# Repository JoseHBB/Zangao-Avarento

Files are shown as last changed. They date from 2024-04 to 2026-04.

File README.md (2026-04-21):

# Zangão Avarento

Wiki pública do projeto de TCC de automação industrial focado no desenvolvimento de um drone de baixo custo controlado por smartphone.

<p align="center">
  Drone final
</p>

## Sobre

O Zangão Avarento nasceu como um projeto de TCC com o objetivo de demonstrar que era possível montar uma plataforma de voo com controle por celular utilizando componentes acessíveis, fabricação própria da placa e desenvolvimento do firmware e do aplicativo.

Este repositório funciona como a documentação pública do projeto. Aqui estão reunidos o histórico de desenvolvimento, os arquivos de eletrônica e PCB, os códigos do Arduino, os arquivos do aplicativo, imagens do processo e o relatório final.

## Navegação da wiki

- [Visão geral do projeto](Projeto.md)
- [Construção mecânica e estrutura](Construcao_Mecanica.md)
- [Firmware e lógica de controle no Arduino](Arduino_Reference.md)
- [Esquema elétrico e PCB no KiCad](KicadSchemePCB_Reference.md)
- [Aplicativo Android](App_Reference.md)
- [Galeria de imagens](Galeria.md)
- [Arquivos e recursos do repositório](Arquivos_e_Recursos.md)

## Estrutura resumida

- `Arduino/`: códigos e rascunhos do firmware.
- `App/`: arquivo-fonte do app no MIT App Inventor e APK gerado.
- `Kicad Scheme-PCB/`: projeto eletrônico e layout da placa.
- `Images/`: imagens de protótipos, placa, estrutura e esquemas.
- `Videos/`: vídeos de testes das funções e demonstração de voo.
- `Apresentação TCC Drone.pptx`: apresentação final do TCC.
- `Relatório.pdf`: versão do relatório final do trabalho.

## Criadores do projeto

- Guilherme Faria da Silva
- João Vinícius da Silva
- José Henrique Batista Borges

## Contato

Qualquer dúvida sobre o projeto:

- [José Henrique](https://github.com/JoseHBB)
- `josehenribb@gmail.com`

## Licença

Este repositório utiliza a licença MIT para fins de estudo, pesquisa, uso pessoal e uso comercial conforme os termos do arquivo [LICENSE](LICENSE).

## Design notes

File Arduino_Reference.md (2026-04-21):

# Firmware E Lógica De Controle No Arduino

## Visão geral

Os arquivos da pasta `Arduino/` registram a base do firmware utilizado para o controle dos motores do drone. O código está organizado como um conjunto de trechos que mostram a estrutura do projeto, a definição dos pinos, a comunicação Bluetooth e as funções de movimento.

## Arquivos disponíveis

- `Arduino/Drone_codigo.ino`: definições principais, variáveis e comunicação serial por software.
- `Arduino/Drone_codigo_functions.ino`: funções de acionamento dos motores.
- `Arduino/Drone_codigo_comments.ino`: descrição textual dos comandos previstos.
- `Arduino/Drone_codigo_base.ino`: `setup()` e `loop()` com leitura Bluetooth e despacho de comandos.

Com a atualização mais recente do repositório, os quatro arquivos acima agora representam o fluxo completo da lógica de controle usada nos testes do projeto.

## Base eletrônica controlada pelo firmware

Pelos arquivos do projeto, o Arduino Nano atua como controlador principal do sistema. O firmware foi pensado para:

- receber comandos de um smartphone;
- interpretar esses comandos por Bluetooth;
- gerar sinais PWM para quatro motores;
- preparar a lógica para controle de movimentação básica.

## Mapeamento dos motores

No arquivo `Drone_codigo.ino`, os motores são associados aos seguintes pinos PWM:

- `motor_frente_dir`: pino `6`
- `motor_traz_dir`: pino `9`
- `motor_frente_esq`: pino `10`
- `motor_traz_esq`: pino `11`

Também foi declarada a interface Bluetooth com:

- `SoftwareSerial HC_06(2,3);`

Isso indica a intenção de usar o módulo HC-06 nos pinos digitais `2` e `3`.

## Variáveis de velocidade

O código separa a intensidade dos movimentos por tipo de ação:

- `vel_subir`
- `vel_descer`
- `vel_xy`
- `vel_giro`

Essa divisão simplifica o ajuste da potência aplicada aos motores em cada situação.

Também aparecem variáveis de estado para controlar o comportamento geral:

- `stoped`: flag de estado para indicar se o sistema está parado.
- `vel_atual`: referência da velocidade atual aplicada ao conjunto.
- `vel_parado` e `vel_start`: base para manter rotação mínima e partida.

## Fluxo de execução do firmware

O funcionamento foi dividido em um fluxo simples e direto:

1. `setup()`
2. inicializa serial USB (`Serial.begin(9600)`)
3. inicializa serial Bluetooth (`HC_06.begin(9600)`)
4. inicializa MPU-6050 (`start_gyro()`)

No `loop()` o código repete o ciclo:

1. faz leitura do sensor (`read_gyro()`)
2. espera um comando Bluetooth chegar (`HC_06.available()`)
3. converte o comando recebido para inteiro (`parseInt()`)
4. usa `switch` para disparar a ação correspondente
5. se o comando não estiver mapeado, executa `parado_no_ar()`

Esse formato deixa o firmware orientado a comando remoto: cada número recebido representa uma função de controle de atitude/movimento.

## Mapeamento de comandos Bluetooth

No `switch` de `Drone_codigo_base.ino`, os códigos são:

- `100`: `start()`
- `101`: `stop()`
- `102`: `subir()`
- `103`: `descer()`
- `104`: `frente()`
- `105`: `traz()`
- `106`: `direita()`
- `107`: `esquerda()`
- `108`: `girar_horario()`
- `109`: `girar_anti_horario()`

## Funções implementadas

As funções presentes em `Drone_codigo_functions.ino` representam os movimentos básicos do drone:

- `start()`: liga todos os motores com potência fixa inicial.
- `stop()`: desliga todos os motores.
- `subir()`: aplica a mesma potência de subida aos quatro motores.
- `descer()`: aplica a mesma potência de descida aos quatro motores.
- `frente()`: aumenta a potência dos motores traseiros.
- `traz()`: aumenta a potência dos motores dianteiros.
- `direita()`: aumenta a potência dos motores da esquerda.
- `esquerda()`: aumenta a potência dos motores da direita.
- `girar_horario()`: altera dois motores para rotação no sentido horário.
- `girar_anti_horario()`: altera dois motores para rotação no sentido anti-horário.

Na prática, os movimentos são obtidos por diferença de PWM entre pares de motores:

- subida/descida: alteração conjunta dos quatro motores;
- translação horizontal: aumenta dois motores e reduz os opostos;
- guinada (yaw): aumenta motores de uma diagonal e reduz os da diagonal contrária.

Esse método é consistente com o comportamento esperado de um quadricóptero em configuração de quatro rotores com controle diferencial de empuxo.

## Leitura do giroscópio/acelerômetro

As funções de sensor já estão presentes no código:

- `start_gyro()`: inicia o MPU-6050 e define faixas de medição/filtro.
- `read_gyro()`: captura aceleração (`a`), rotação (`g`) e temperatura (`temp`).

Mesmo sem malha de controle fechada implementada nesta versão, essa base já prepara o firmware para evolução com estabilização automática e correção por realimentação.

## Lógica documentada nos comentários

O arquivo `Drone_codigo_comments.ino` resume os seis blocos de comportamento previstos:

1. ligar todos os motores em velocidade pré-definida;
2. desligar todos os motores;
3. subir;
4. descer;
5. movimentação horizontal nos eixos `X` e `Y`;
6. movimentação rotativa.

## Escopo do que está no repositório

Os arquivos disponíveis representam a implementação funcional de controle por comandos Bluetooth e organização da lógica por funções de voo/movimento. A parte de estabilização por sensor ainda aparece como base de leitura e preparação da arquitetura.

A documentação é útil para entender a arquitetura adotada:

- um comando vindo do app;
- a interpretação desse comando no Arduino;
- a seleção da função de movimento;
- o ajuste da potência dos motores via PWM.

## Relação com o hardware

O firmware conversa diretamente com a eletrônica descrita em [KicadSchemePCB_Reference.md](KicadSchemePCB_Reference.md):

- os sinais PWM saem do Arduino Nano;
- esses sinais acionam os MOSFETs da placa;
- os MOSFETs controlam a alimentação dos motores;
- o HC-06 recebe os comandos do aplicativo;
- o giroscópio foi previsto como fonte de dados para evolução do controle.

## Leitura recomendada

- [Visão geral do projeto](Projeto.md)
- [Esquema elétrico e PCB no KiCad](KicadSchemePCB_Reference.md)
- [Aplicativo Android](App_Reference.md)

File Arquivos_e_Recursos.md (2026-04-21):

# Arquivos E Recursos Do Repositório

## Objetivo desta página

Esta página resume o que existe no repositório e para que serve cada grupo de arquivos. A ideia é facilitar o uso deste projeto como uma wiki pública.

## Pastas principais

### `Arduino/`

Arquivos relacionados ao firmware e à lógica de controle:

- `Drone_codigo.ino`
- `Drone_codigo_base.ino`
- `Drone_codigo_comments.ino`
- `Drone_codigo_functions.ino`

Leitura recomendada: [Arduino_Reference.md](Arduino_Reference.md)

### `App/`

Arquivos do aplicativo Android:

- `Controlador_de_motor_via_BT.aia`
- `Controlador_de_motor_via_BT.apk`

Leitura recomendada: [App_Reference.md](App_Reference.md)

### `Kicad Scheme-PCB/`

Arquivos do projeto eletrônico e da placa:

- `drone_pcb_V1.4.kicad_sch`
- `drone_pcb_V1.4.kicad_pcb`
- `drone_pcb_V1.4.kicad_pro`
- `drone_pcb_V1.4.kicad_prl`

Leitura recomendada: [KicadSchemePCB_Reference.md](KicadSchemePCB_Reference.md)

### `Images/`

Imagens usadas para documentar a evolução do projeto, a estrutura e a placa:

- `Projeto - 2022.jpg`
- `Drone_Cima_Old.png`
- `Drone_Cima_New.png`
- `Drone_Frente.jpg`
- `Carcaça.jpg`
- `Hélice.jpg`
- `Esquema_Eletrico.png`
- `PCB_Blueprint.png`
- `PCB_Front.jpg`
- `PCB_Back.jpg`
- `PCB_Only.jpg`

Leitura recomendada: [Galeria.md](Galeria.md)

### `Videos/`

Vídeos de demonstração e validação do funcionamento:

- `Video - Teste funções.mp4`
- `Video - Voo.mp4`

Leitura recomendada: [Galeria.md](Galeria.md)

### `Apresentação TCC Drone.pptx`

Arquivo da apresentação final do TCC usado para defesa e exposição do projeto.

## Arquivos de documentação

- `README.md`: página inicial da wiki.
- `Projeto.md`: visão geral e histórico do TCC.
- `Construcao_Mecanica.md`: documentação da parte estrutural.
- `Arduino_Reference.md`: referência do firmware.
- `KicadSchemePCB_Reference.md`: referência da eletrônica e PCB.
- `App_Reference.md`: referência do aplicativo.
- `Galeria.md`: central de imagens do projeto.

## Arquivos adicionais

- `Relatório.pdf`: relatório final do TCC.
- `Apresentação TCC Drone.pptx`: apresentação final do TCC.
- `Planilha com os preços 2022.xlsx`: levantamento de custos e componentes.
- `LICENSE`: licença do repositório.
- `Videos/Video - Teste funções.mp4`: demonstração das funções de comando.
- `Videos/Video - Voo.mp4`: demonstração prática de voo.

## Como usar este repositório

Se o objetivo for entender o projeto como um todo, a melhor sequência é:

1. começar por [README.md](README.md);
2. seguir para [Projeto.md](Projeto.md);
3. consultar as páginas específicas de mecânica, firmware, eletrônica e app;
4. usar [Galeria.md](Galeria.md) para apoio visual;
5. consultar a apresentação em `Apresentação TCC Drone.pptx`;
6. abrir o `Relatório.pdf` para a versão acadêmica consolidada.

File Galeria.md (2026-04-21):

# Galeria De Imagens

## Protótipo inicial

<p align="center">
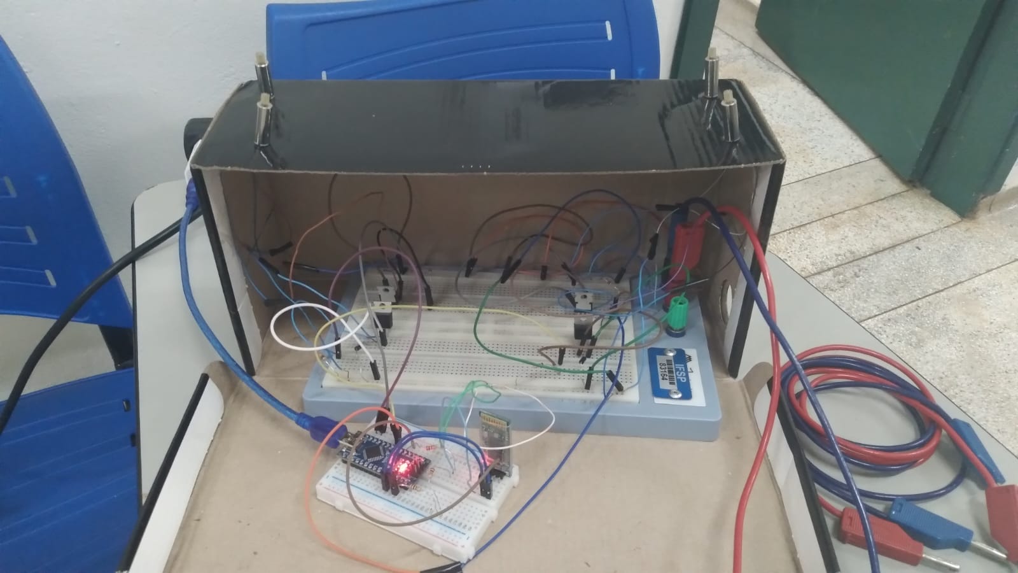
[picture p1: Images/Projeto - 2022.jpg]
Protótipo 2022
  <br/>
  Estrutura inicial usada para demonstrar o controle dos motores.
</p>

## Evolução da estrutura

<p align="center">
  Drone vista superior antiga<br/>
  Versão anterior da estrutura.
</p>

<p align="center">
  Drone vista superior nova<br/>
  Versão mais refinada da estrutura.
</p>

<p align="center">
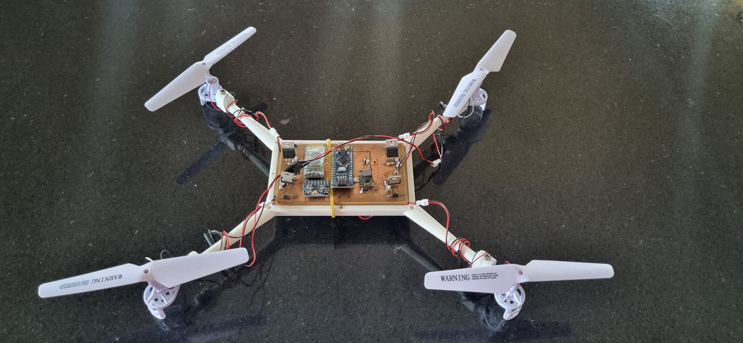
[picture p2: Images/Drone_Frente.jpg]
Drone vista frontal
  <br/>
  Vista frontal do drone.
</p>

## Peças mecânicas

<p align="center">
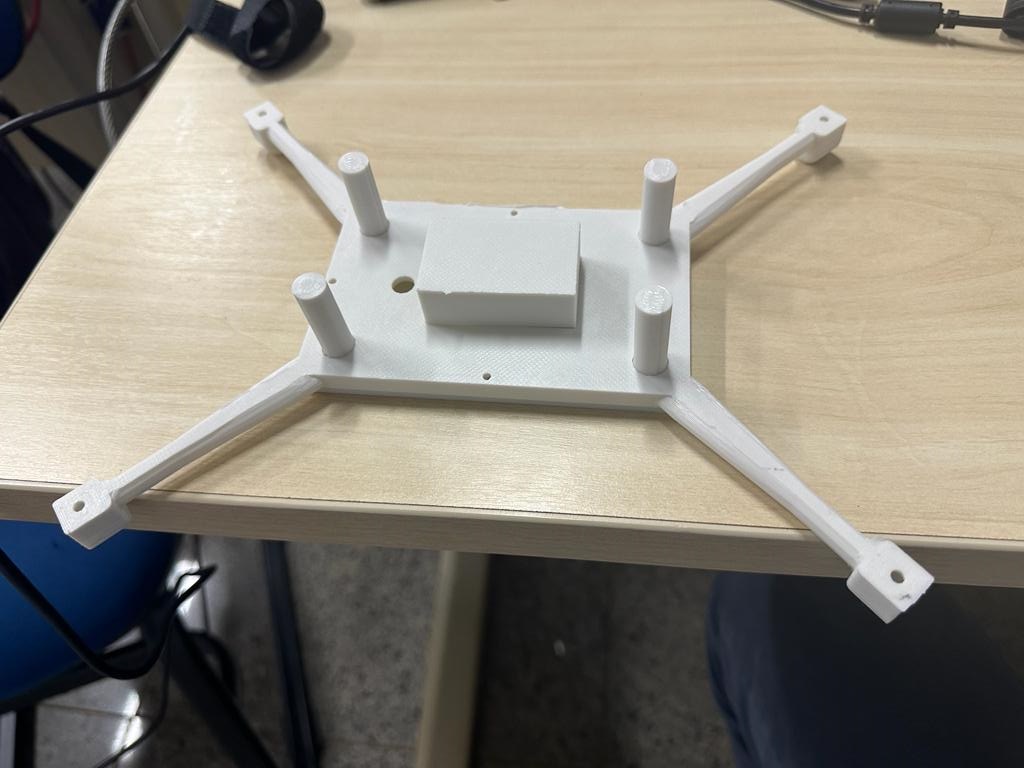
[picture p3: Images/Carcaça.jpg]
Carcaça
  <br/>
  Carcaça do projeto.
</p>

<p align="center">
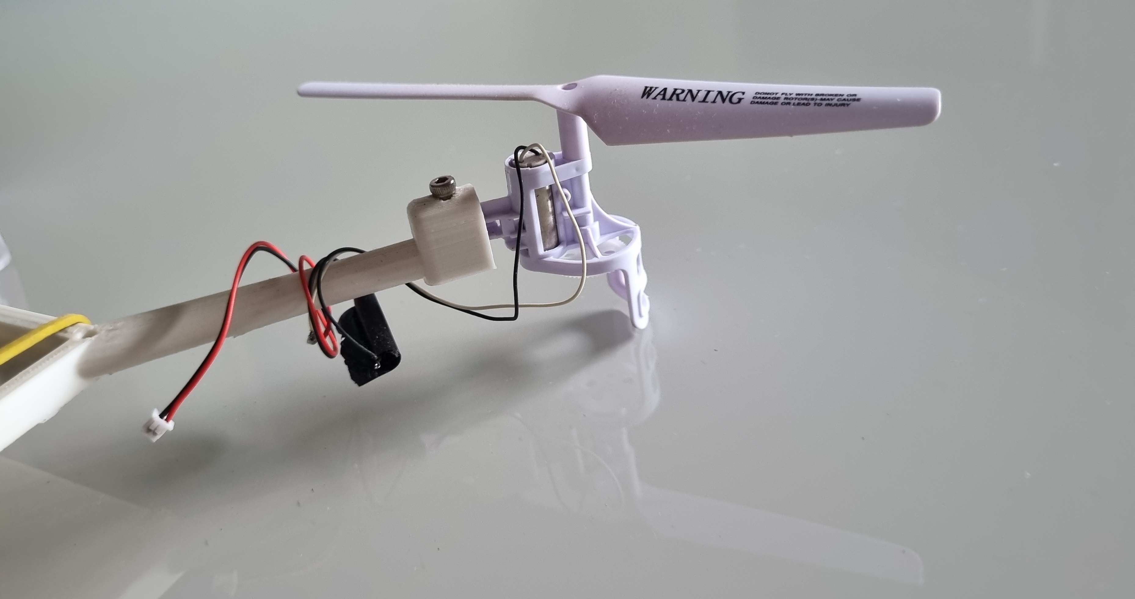
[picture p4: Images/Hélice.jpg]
Helice
  <br/>
  Hélice utilizada.
</p>

## Eletrônica

<p align="center">
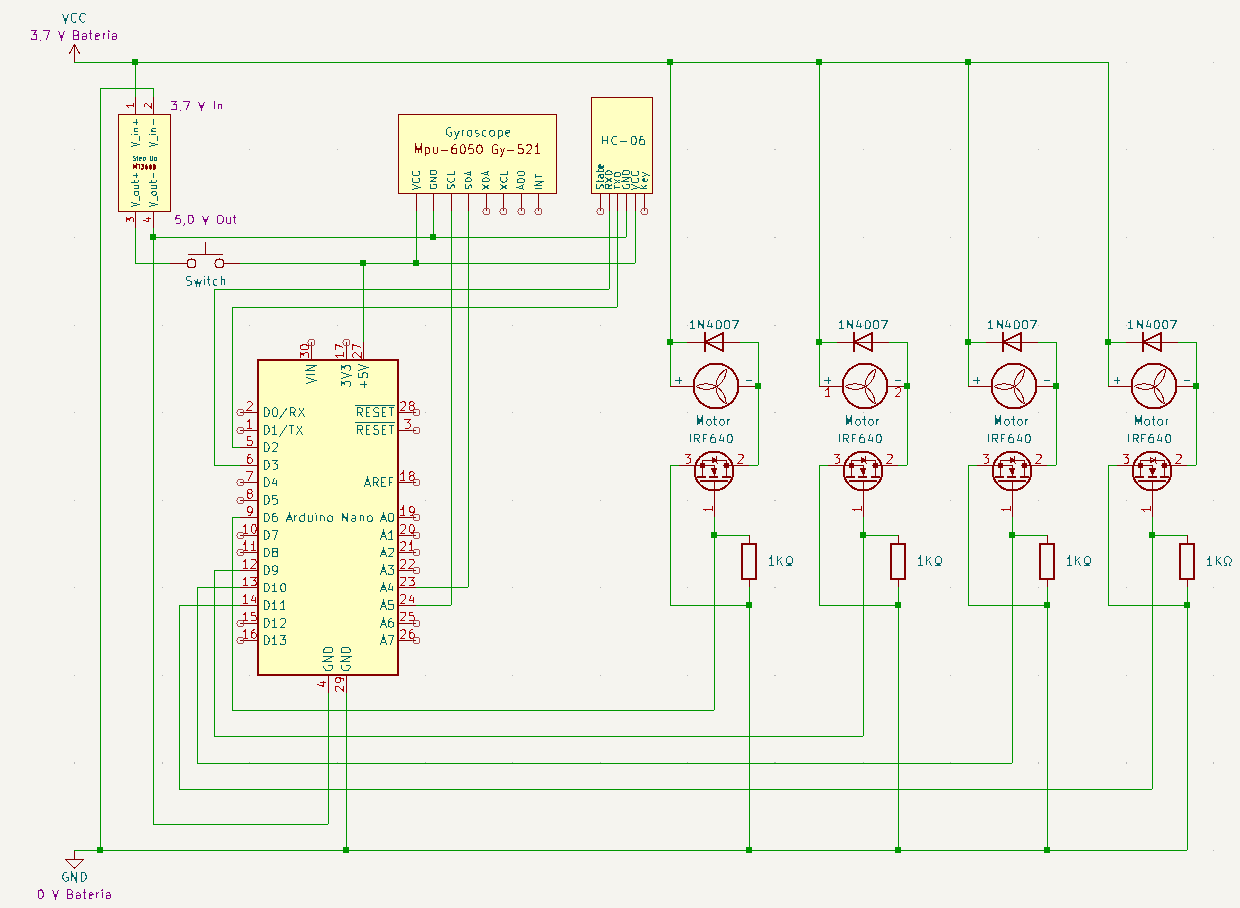
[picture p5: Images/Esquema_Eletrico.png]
Esquema elétrico
  <br/>
  Esquema elétrico do sistema.
</p>

<p align="center">
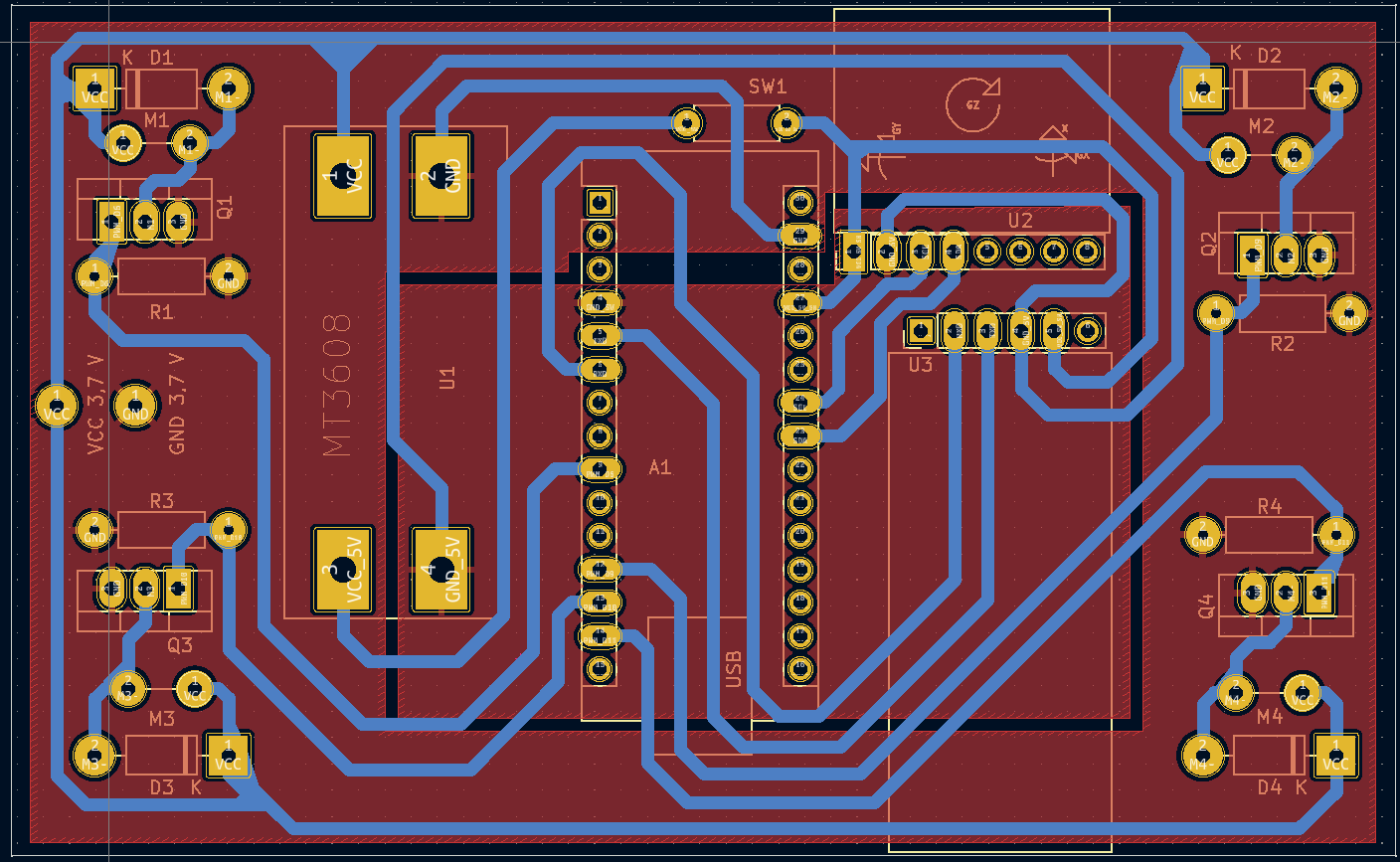
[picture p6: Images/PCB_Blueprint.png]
Blueprint PCB
  <br/>
  Blueprint da PCB.
</p>

<p align="center">
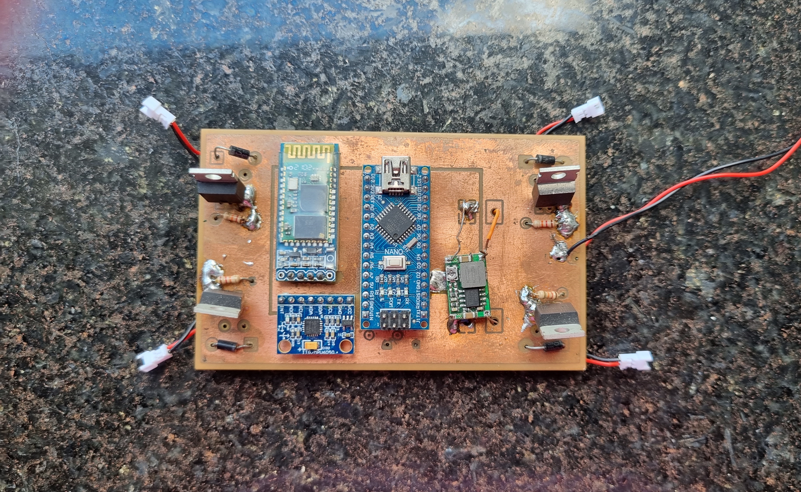
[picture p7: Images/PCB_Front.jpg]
PCB front
  <br/>
  Face frontal da placa.
</p>

<p align="center">
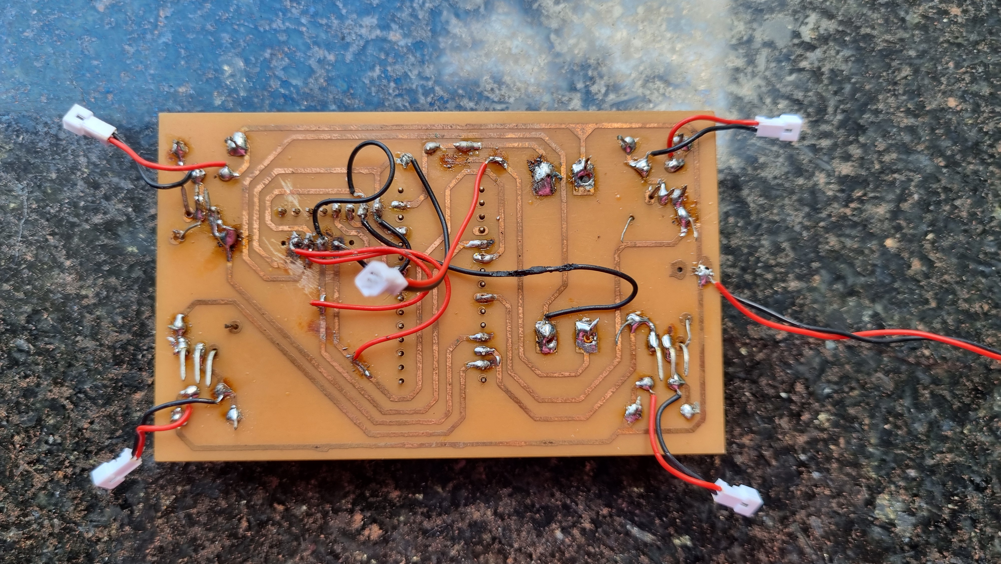
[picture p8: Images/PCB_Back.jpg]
PCB back
  <br/>
  Face traseira da placa.
</p>

<p align="center">
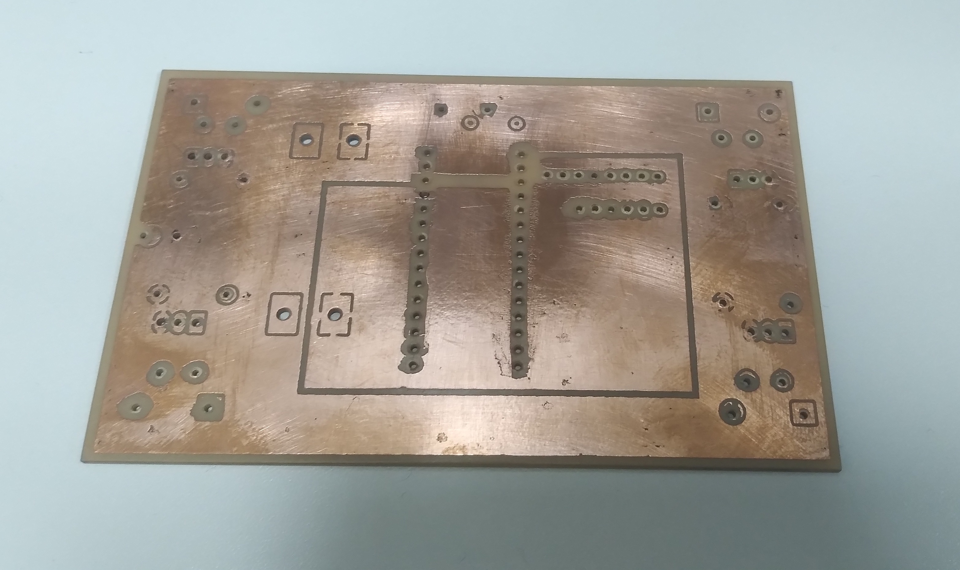
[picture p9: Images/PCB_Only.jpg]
PCB only
  <br/>
  PCB isolada.
</p>

## Vídeos de funcionamento

Os testes e demonstrações mais recentes também estão documentados em vídeo:

- [Teste das funções de controle](Videos/Video%20-%20Teste%20fun%C3%A7%C3%B5es.mp4)
- [Demonstração de voo](Videos/Video%20-%20Voo.mp4)

## Navegação relacionada

- [Visão geral do projeto](Projeto.md)
- [Construção mecânica e estrutura](Construcao_Mecanica.md)
- [Esquema elétrico e PCB no KiCad](KicadSchemePCB_Reference.md)

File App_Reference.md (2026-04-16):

# Aplicativo Android

## Visão geral

O controle do Zangão Avarento foi pensado para ser feito por smartphone, mantendo o projeto alinhado com a proposta de baixo custo. Em vez de um rádio controle dedicado, o grupo utilizou comunicação Bluetooth entre o celular e o sistema embarcado.

## Arquivos disponíveis

Na pasta `App/` existem dois artefatos:

- `App/Controlador_de_motor_via_BT.aia`: projeto editável do MIT App Inventor.
- `App/Controlador_de_motor_via_BT.apk`: aplicativo Android compilado para instalação.

## Função do aplicativo no projeto

O aplicativo atua como interface do usuário para enviar comandos ao Arduino por meio do módulo HC-06. Dentro da arquitetura do projeto, ele cumpre três papéis:

- oferecer um meio simples de controle;
- substituir um controle remoto dedicado;
- demonstrar integração entre software mobile e sistema embarcado.

## Tecnologia utilizada

O desenvolvimento foi feito no MIT App Inventor, uma plataforma visual bastante adequada para protótipos educacionais e experimentais. Isso combina com a proposta do TCC porque reduz a barreira de desenvolvimento do lado mobile e acelera a criação da interface.

## Relação com o firmware

O app depende da lógica descrita em [Arduino_Reference.md](Arduino_Reference.md):

- o celular envia comandos;
- o módulo Bluetooth HC-06 recebe esses dados;
- o Arduino interpreta a informação recebida;
- o firmware ajusta os motores conforme a ação desejada.

## Relação com a eletrônica

No projeto eletrônico documentado em [KicadSchemePCB_Reference.md](KicadSchemePCB_Reference.md), o módulo Bluetooth identificado é o `HC-06`. Isso confirma que a aplicação Android foi pensada especificamente para controle sem fio via Bluetooth serial.

## Observação sobre edição

O arquivo `.aia` é o ponto de partida para estudar ou alterar o aplicativo. O `.apk` é útil para instalação e demonstração, mas não substitui o arquivo-fonte do App Inventor.

## Leitura recomendada

- [Visão geral do projeto](Projeto.md)
- [Firmware e lógica de controle no Arduino](Arduino_Reference.md)
- [Arquivos e recursos do repositório](Arquivos_e_Recursos.md)

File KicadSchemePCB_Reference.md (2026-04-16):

# Esquema Elétrico E PCB No KiCad

## Visão geral

O projeto eletrônico do Zangão Avarento foi desenvolvido no KiCad 6.0 e reúne a parte de alimentação, controle, comunicação e acionamento dos motores. O repositório guarda tanto os arquivos editáveis do projeto quanto imagens exportadas do esquema e da placa.

## Arquivos disponíveis

Na pasta `Kicad Scheme-PCB/` estão os arquivos principais:

- `drone_pcb_V1.4.kicad_sch`: esquema elétrico.
- `drone_pcb_V1.4.kicad_pcb`: layout da placa.
- `drone_pcb_V1.4.kicad_pro`: projeto KiCad.
- `drone_pcb_V1.4.kicad_prl`: preferências locais do projeto.

## Arquitetura eletrônica identificada

Pelos arquivos do KiCad, a placa foi estruturada em torno dos seguintes blocos:

- `Arduino Nano`: controlador principal.
- `HC-06`: comunicação Bluetooth com o smartphone.
- `MPU-6050 / GY-521`: módulo de giroscópio e acelerômetro.
- `MT3608`: conversor step-up para elevação da tensão.
- `4 x IRF640`: MOSFETs para acionamento dos motores.
- `Switch`: chave para comutação da alimentação.

## Componentes principais

### Arduino Nano

O esquema identifica o microcontrolador como `A1`, usando o módulo `Arduino Nano v3.x`. Ele centraliza a leitura dos comandos e a geração dos sinais PWM.

### Bluetooth HC-06

O módulo `U3` é um `HC-06`, responsável pela comunicação serial Bluetooth entre o app e o Arduino.

### Giroscópio / acelerômetro

O módulo `U2` aparece como `Gyroscope`, com texto interno identificando `Mpu-6050 Gy-521`. Isso indica a intenção de usar dados de orientação e aceleração como apoio ao controle do voo.

### Alimentação

O módulo `U1` é um `MT3608`, com indicação de entrada em `3,7 V` e saída em `5,0 V`. Isso mostra a estratégia de elevar a tensão para alimentar a lógica do sistema.

### Estágio de potência

Os transistores `Q1`, `Q2`, `Q3` e `Q4` são `IRF640`. No contexto do projeto, esses MOSFETs atuam como chaveamento dos motores a partir dos sinais PWM do Arduino.

## Conexões relevantes observadas

No arquivo da placa aparecem as seguintes redes de controle:

- `PWM_D6`
- `PWM_D9`
- `PWM_D10`
- `PWM_D11`
- `SCL`
- `SDA`
- `RXD`
- `TXD`

Isso está alinhado com a lógica documentada no firmware:

- quatro saídas PWM para os motores;
- linhas de comunicação serial para o Bluetooth;
- barramento I2C para o módulo sensor.

## Imagens da eletrônica

<p align="center">
  Esquema elétrico<br/>
  Esquema elétrico do projeto.
</p>

<p align="center">
  Blueprint da PCB<br/>
  Blueprint da placa desenvolvido no KiCad.
</p>

<p align="center">
  Face frontal da PCB<br/>
  Face frontal da placa.
</p>

<p align="center">
  Face traseira da PCB<br/>
  Face traseira da placa.
</p>

<p align="center">
  PCB isolada<br/>
  Vista da placa fora do conjunto.
</p>

## Papel da PCB no projeto

A placa organiza em um único conjunto:

- o controlador principal;
- os módulos auxiliares;
- a distribuição da alimentação;
- o estágio de chaveamento dos motores.

Isso melhora a montagem, reduz ligações soltas e deixa o protótipo mais próximo de um sistema embarcado completo.

## Leitura recomendada

- [Visão geral do projeto](Projeto.md)
- [Firmware e lógica de controle no Arduino](Arduino_Reference.md)
- [Aplicativo Android](App_Reference.md)

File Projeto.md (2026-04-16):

# Visão Geral Do Projeto

## Objetivo

O Zangão Avarento foi desenvolvido como um TCC na área de automação industrial com a proposta de construir um drone experimental de baixo custo controlado por smartphone. A ideia central era integrar mecânica, eletrônica, programação embarcada e comunicação sem fio em uma única plataforma.

## Proposta técnica

O projeto foi organizado em quatro frentes principais:

- `Estrutura mecânica`: carcaça, suporte dos motores e adaptação das hélices.
- `Eletrônica`: esquema elétrico, condicionamento de alimentação e placa de circuito impresso.
- `Controle embarcado`: código em Arduino para acionar os motores e receber comandos.
- `Aplicativo`: interface mobile criada no MIT App Inventor para enviar comandos via Bluetooth.

## Linha do tempo

### Etapa inicial - 2022

Em 2022 o grupo desenvolveu uma prova de conceito para validar o controle dos motores por smartphone. Nessa fase, o sistema ainda não era um drone completo: tratava-se de uma estrutura simples com quatro motores, controlados por um Arduino Nano e por um aplicativo Android via Bluetooth.

<p align="center">
  Protótipo de 2022<br/>
  Protótipo inicial utilizado para demonstrar o acionamento dos motores.
</p>

Ainda nesse período foi criada uma planilha de custos para levantar os componentes necessários:

- [Planilha com os preços 2022.xlsx](Planilha%20com%20os%20pre%C3%A7os%202022.xlsx)

## Evolução em 2023

Com a base validada em 2022, o trabalho passou a focar na construção de uma versão mais completa e melhor documentada. As decisões principais dessa fase foram:

- Produzir uma carcaça compatível com os conjuntos de motor e hélice disponíveis.
- Refazer o esquema elétrico para acomodar potência e lógica no mesmo projeto.
- Projetar uma PCI própria para organizar os componentes.
- Manter o controle via smartphone para preservar a proposta de baixo custo.
- Preparar o sistema para uso de sensores como giroscópio/acelerômetro.

## O que foi desenvolvido

### Estrutura e prototipagem

A construção mecânica passou por ajustes porque os primeiros motores e hélices comprados separadamente não se encaixavam de forma adequada. A solução foi utilizar conjuntos prontos de hélices, motores e suportes, reduzindo o esforço de adaptação mecânica e acelerando os testes.

Veja mais em [Construção mecânica e estrutura](Construcao_Mecanica.md).

### Eletrônica e PCB

O esquema elétrico e a placa foram desenvolvidos no KiCad 6.0. A eletrônica reúne:

- Arduino Nano como controlador principal.
- Módulo Bluetooth HC-06 para comunicação com o aplicativo.
- Módulo giroscópio MPU-6050/GY-521 para sensoriamento.
- Conversor step-up MT3608 para alimentação em 5 V.
- Quatro MOSFETs IRF640 para acionamento dos motores.

<p align="center">
  Esquema elétrico<br/>
  Esquema elétrico desenvolvido no KiCad.
</p>

Detalhes completos em [Esquema elétrico e PCB no KiCad](KicadSchemePCB_Reference.md).

### Firmware

O firmware disponível no repositório mostra a lógica base de acionamento dos quatro motores por PWM e a separação das funções de comando, como subir, descer, deslocar e girar.

Detalhes em [Firmware e lógica de controle no Arduino](Arduino_Reference.md).

### Aplicativo

O aplicativo foi desenvolvido no MIT App Inventor e é responsável pelo envio dos comandos ao sistema via Bluetooth. O repositório inclui tanto o projeto editável quanto o APK gerado.

Detalhes em [Aplicativo Android](App_Reference.md).

## Resultado do repositório

Este repositório preserva os principais artefatos do TCC como uma base de consulta pública. O objetivo não é apenas guardar os arquivos finais, mas também permitir que outras pessoas entendam como o projeto foi estruturado e possam estudar ou reaproveitar partes dele.

Para uma visão consolidada dos arquivos, consulte [Arquivos e recursos do repositório](Arquivos_e_Recursos.md).

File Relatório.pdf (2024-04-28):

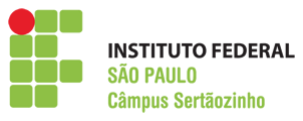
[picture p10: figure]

### DRONE ECONÔMICO CONTROLADO POR SMARTPHONE

GUILHERME F. SILVA¹

, JOÃO V. SILVA²

, JOSÉ H. B. BORGES³

1 Graduando em Automação Industrial, IFSP, Câmpus Sertãozinho, guilherme.faria@aluno.ifsp.edu.br. 2 Graduando em Automação Industrial, IFSP, Câmpus Sertãozinho, joao.vinicius@aluno.ifsp.edu.br. 3 Graduando em Automação Industrial, IFSP, Câmpus Sertãozinho, j.borges@aluno.ifsp.edu.br.

Área de conhecimento (Tabela CNPq): 3.12.03.03-5 Projeto de Estruturas Aeroespaciais

RESUMO: Devido o seu pequeno tamanho, boa performance e simples design, o uso de quadricópteros tem se proliferado e detém as mais diversas aplicações, desde militares até relacionadas à área da saúde, entretanto tendo sempre um alto custo. Este trabalho tem como propósito central: apresentar uma pesquisa que foi desenvolvida, com a proposta de fabricar um drone de baixo custo com peças que podem ser encontradas facilmente. Neste estudo, é feito um pequeno resumo sobre como funciona o voo de um drone, é discutido o custo desse projeto e é descrita uma forma de que o controle do voo pode ser feito de forma mais barata, utilizando MOSFETs, PWM, controle por Smartphone via Bluetooth e Arduino. Por fim, é proposta a elaboração de uma PCI (Placa de Circuito Impresso) e a impressão de um frame 3D para o projeto e os resultados obtidos são analisados.

PALAVRAS-CHAVE: Baixo custo; PCI; Bluetooth; Arduino; PWM;

BUDGET DRONE CONTROLLED BY SMARTPHONE

ABSTRACT: Due to its small size, great performance and simple design, the use of quadcopters has grown and has lots of applications, from military to even health, however always having a high cost. This project has as its main purpose: introduce research that is being developed, with the goal to make a low-cost drone with parts that can be found easily. In this research there is a summary of how a drone flies, the cost of the project and how the drone flight can be controlled using cheaper options with MOSFETs, PWM, smartphone control with Bluetooth and an Arduino. Finally, it is proposed the elaboration of a PCB (Printed Circuit Board) and the impression of the frame with 3D printing and the results already obtained are analyzed.

KEYWORDS: Low cost; PCB; Bluetooth; Arduino; PWM.

INTRODUÇÃO

Em 1977, quando surgiram os primeiros modelos de drone como conhecemos hoje, estes veículos eram difíceis de controlar, sendo necessárias 30 pessoas para isso, e buscavam aplicações bélicas. Atualmente, com os avanços tecnológicos, esses veículos foram se tornando mais simples de serem controlados, menores e começaram a ser usados para diversos propósitos comerciais além dos militares, como nos setores agrícola e logístico, facilitando tarefas e agilizando a realização de alguns processos. Vale ressaltar que devido sua alta estabilidade e existência nos mais diversos tamanhos, há inúmeras possibilidades de expansão e novas funcionalidades para estas tecnologias, podendo integrá-los com o uso de inteligências artificiais para maximizar a eficiência de seu uso (Calixto, 2022). Devido a sua ampla aplicabilidade, mostra-se importante entender e dominar as técnicas por trás desse veículo para, dessa forma, ser atuante nessa nova era de inovações. Um drone comum (quadricóptero) possui 4 braços, podendo conter também 6 ou 8, com um motor e uma hélice em cada um desses braços. Nos modelos mais simples, dois motores giram para o sentido horário e os outros dois giram no sentido oposto e é isso que dá a estabilidade necessária para a aeronave. Apenas controlando a velocidade desses 4 motores e com sensores de aceleração e de giro, é possível realizar todas as manobras necessárias para seu voo e garantir seu equilíbrio. Entretanto, toda esta tecnologia tem um custo consideravelmente elevado, podendo até passar de 20 mil reais.
Portanto, a ideia desse projeto é, além de dominar toda essa ciência que só tende a se proliferar, mostrar que é possível construir um drone estável capaz de executar um voo simples através de equipamentos eletrônicos de baixo custo e demonstrar que os conceitos utilizados na construção deles podem ser utilizados como uma ferramenta didática para o ensino de noções de eletricidade e eletrônica.

MATERIAL E MÉTODOS

Os materiais utilizados foram: Bateria 3,7V 1000mAh; Arduino nano; Módulo Bluetooth; Acelerômetro e Giroscópio; Motores 3,7V; 4 Hélices; 4 Mosfets; 4 Resistores de 1KΩ; 4 Diodos IN4007; 4 Parafusos para hélice; 4 Engrenagens para conexão do motor com a hélice; 4 Protetores de hélice; Trem de pouso; Switch de Liga/Desliga; Regulador de tensão Step-Up; Filamento para impressora 3D;
Os métodos usados durante a pesquisa foram: Kicad para desenvolvimento do esquema elétrico e PCB; Software 3D para modelagem da carcaça; Impressão 3D da carcaça; Programação de um algoritmo que com o uso do giroscópio mantenha o drone estável (implementação do PID); Programação de aplicativo para smartphone para controle do drone via bluetooth.

RESULTADOS E DISCUSSÃO

Inicialmente, foi pesquisado sobre a teoria de um voo: basicamente, com o aumento da velocidade de rotação das hélices, obtém-se menor pressão sobre elas, surgindo um vetor resultante de força para cima chamada de empuxo (Silva; Cordeiro, 2011).
Um aspecto muito positivo e que faz que os drones tenham uma ampla aplicação é sua simples manobrabilidade, pois apenas com o controle independente da velocidade de rotação de cada hélice, é possível que a aeronave se desloque sob uma ampla variedade de trajetórias. Vale destacar que em um quadricóptero, dois rotores giram no sentido horário, enquanto os outros dois giram no sentido anti-horário, conforme figura 1.
Dessa forma, para velocidades iguais nos quatro rotores, o drone se deslocará verticalmente, dependendo do empuxo para determinar o sentido. Se a velocidade dos rotores R1 e R4 forem maiores que as dos rotores R2 e R3, o drone gira no sentido anti-horário e, caso o contrário aconteça, o drone girará no sentido horário. O voo nivelado para frente ou para trás acontece devido à variação das velocidades de duas hélices vizinhas lateralmente (R1 e R3 ou R2 e R4). Vale destacar que, caso deseje que o drone se mantenha no mesmo plano enquanto realiza estes movimentos, é necessário aumentar a velocidade de dois deles e diminuir a velocidade dos outros, de modo a impedir que o empuxo varie. Todas as outras manobras podem ser realizadas a partir de outras combinações. Tendo esse referencial bibliográfico em mente, começaram as pesquisas sobre projetos caseiros de drones.

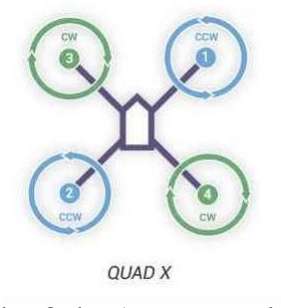
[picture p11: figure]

FIGURA 1. Estrutura de um Quadrotor (Romero; Pozo; Rosales, 2014).

A maioria dos projetos de drones caseiros produzidos encontrados nas mais diversas pesquisas realizadas envolviam a utilização de Controladores Eletrônicos de Velocidade (ESCs) para o controle da velocidade dos motores, o uso de rádio transmissor para controlar o movimento dos drone e o uso do ESP32 como controlador principal do drone, tecnologias mais sofisticadas, complicadas e de maior custo. Na elaboração e execução desse projeto, optou-se pelo uso de materiais mais baratos e com funcionamento já conhecido, porque, como esses materiais e técnicas eram ensinados durante as aulas, poderia se utilizar da construção do drone como ferramenta didática, ampliando o conhecimento adquirido para além da sala de aula. Com esse intuito, foram utilizados MOSFETs (transistores de efeito de campo semicondutor de óxido metálico) e o conceito de PWM (Modulação por largura de pulso) para controlar a velocidade dos motores, celulares foram usados para controlar o movimento do drone e o ESP32 foi substituído pelo Arduino.
Na compra dos equipamentos, foram escolhidos os materiais que mais se parecessem com os utilizados no projeto-base, o projeto que foi utilizado como modelo para a elaboração do nosso, e que não tivessem um custo tão elevado. Foi muito importante na compra e escolha dos materiais, o peso das peças, buscando que o drone tivesse o menor peso possível. Devido ao fato de não terem sido encontradas todas as peças idênticas às originais, o projeto passou por mais algumas adaptações. Com essas adaptações, o nosso projeto teve um custo de apenas R$247,38, enquanto o projeto que serviu de inspiração para elaboração do nosso gastou R$424,80, uma queda de mais de 40% do valor inicial, sendo realmente um drone de baixo custo de acordo com a ideia inicial do projeto (MacajoTecno, 2018). Conforme os equipamentos chegavam, os mesmos eram testados na protoboard isoladamente, de modo que pudéssemos entender o funcionamento de cada um deles. A partir da experiência adquirida com o teste de cada uma das peças junto ao conhecimento conquistado durante o levantamento bibliográfico, foi possível começar a compreender como todo aquele circuito funcionaria em conjunto e como, posteriormente, o drone funcionaria na prática.
O principal circuito do drone é o circuito do controle dos motores (vide figura 2), pois como citado anteriormente, é a partir dele que é possível que o drone realize todas as suas manobras, por isso a maior parte dos testes foram focados nesse circuito. Neste circuito, o Arduino emite um sinal PWM, ou seja, um sinal digital que consegue pela variação da largura da onda quadrada, variar a tensão emitida. Este sinal enviado para o MOSFET gera a tensão gate-dreno e, conforme esta tensão aumenta, o MOSFET também gera uma maior tensão gate-source para o motor, logo o MOSFET serve como uma chave de controle. Neste circuito, há também um diodo que protege o motor contra corrente reversa, o que acarretaria no mau funcionamento do mesmo. Um problema encontrado nas medições realizadas é que, mesmo definindo o mesmo valor para potência dos motores no Arduino, eles não giravam com a mesma velocidade, pois, por algum motivo não descoberto, eles não recebem a mesma tensão. Portanto, foram realizados alguns testes e mudanças no código para regular as tensões manualmente. Entretanto, esse tipo de controle manual não é ideal, devido ao motivo de que o fator de correção varia, sendo maior ou menor de acordo com a velocidade desejada. Logo, outra maneira possível, porém pouco aprofundada nesse trabalho, de balancear a velocidade dos motores para que o drone se mantenha estável é com o uso do controle PID (proporcional, integrativo, derivativo). Essa, que é uma das formas mais antigas de controle, funciona simplificadamente da seguinte forma: com a utilização dos dados do acelerômetro e do giroscópio, pode-se definir o ângulo de inclinação do drone em relação a cada um dos eixos x, y e z e, com o erro encontrado, é calculado um fator de correção a partir de uma equação matemática que consiste em 3 partes: a parte proporcional, derivativa, integrativa e seus respectivos ganhos. Esse fator de correção é aplicado no sinal PWM emitido pelo Arduino, dessa forma, balanceando devidamente o drone. Vale destacar que para cada um dos eixos é definido um diferente fator de correção (Masoud et al., 2016).

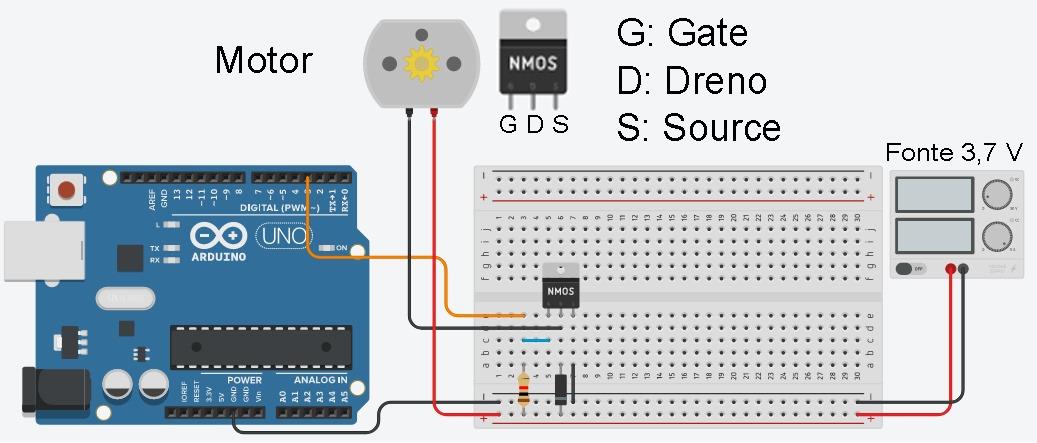
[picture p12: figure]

FIGURA 2. Circuito do controle do motor feito no software TinkerCad.
Nesta figura, os fios vermelhos representam os positivos, os pretos os negativos, o amarelo envia o sinal PWM do Arduino e o azul o transmite para o MOSFET.

Houveram alguns experimentos envolvendo os sensores e o que poderia futuramente vir a ser um controle PID: nestes ensaios, utilizava-se da leitura do giroscópio e do acelerômetro para definir a aceleração do drone e, a partir dela, definir quais motores deveriam aumentar ou diminuir sua potência, logo, quando o drone era inclinado para a esquerda, por exemplo, os motores da esquerda aumentavam sua potência para que, dessa forma, o drone fosse para a direita, buscando sempre a estabilidade da equipamento no plano. Vale ressaltar que essa é uma aplicação simples e que um controle PID completo apresenta uma complexidade superior e exige um tempo maior para realizar os testes necessários para sua aplicação, por isso não houve a execução completa desse tipo de controle durante o projeto.
Outro problema encontrado durante os testes dos componentes elétricos foi que a bateria adquirida não apresentava uma taxa C (C-Rate) adequada, ou seja, ela não tinha a capacidade de carga e descarga adequada e, com isso, a bateria não era capaz de fazer todos os motores girarem em sua potência máxima, pois o consumo deles nessa situação é relativamente elevado, utilizando de mais de 3 Amperes de corrente. Devido a esse empecilho encontrado, a maioria dos testes foram realizados com o uso de uma fonte de bancada, configurada em 3,7 Volts.
Com os componentes e os circuitos já testados, no início deste ano, foi elaborada uma placa de circuito impresso (PCI) - ou, no inglês, Printed Circuit Board (PCB), o software KICAD foi utilizado para confeccionar a mesma. Como normalmente é feito na realização de PCIs, primeiramente o esquema elétrico foi desenhado e depois foi realizado o layout do circuito impresso.
Com a ajuda do professor Ferdinando, a PCI foi confeccionada na escola. Inicialmente, houve a tentativa de utilizar a prototipadora para confeccionar a PCI, entretanto como nossa placa apresentava certo grau de complexidade e a máquina estava com defeito, o método caseiro foi utilizado para a realização da PCI: o layout da placa foi impresso, depois o desenho foi transferido para a placa de fenolite com o ferro de passar, após isso o cobre da placa foi corroído com o uso de percloreto de ferro, restando ao fim apenas o cobre protegido pelo papel, ou seja, apenas as trilhas da placa.

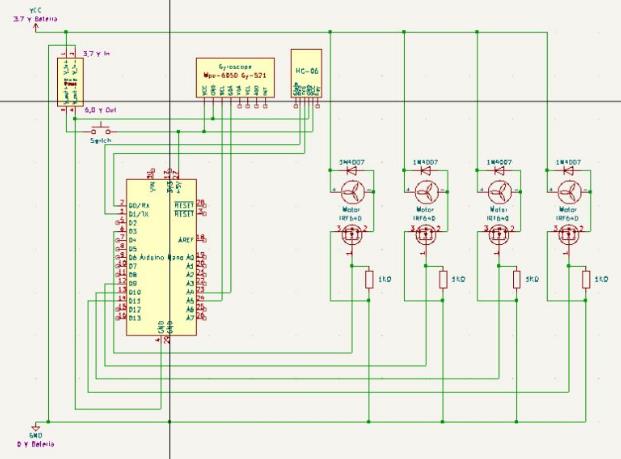
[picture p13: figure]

FIGURA 3. Circuito elétrico feito no software KICAD.

Com a placa já pronta, os dispositivos foram soldados nela e, após isso, também foi testada a continuidade das trilhas e se os circuitos estavam funcionando como esperado.

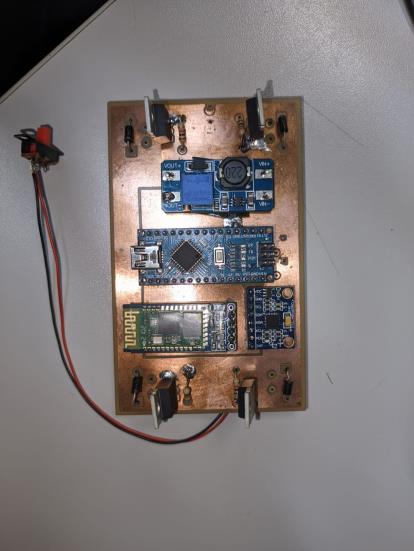
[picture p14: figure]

FIGURA 4. Placa de circuito impresso pronta com dispositivos soldados.

Por fim, após a fabricação da placa e a certificação de seu bom funcionamento, com o auxílio do nosso orientador e professor João Paulo e utilizando o software Fusion, foi elaborado um frame bem simples, de forma que o mesmo tenha uma boa aplicabilidade, além de ter o menor peso possível. O frame foi feito pela impressora 3D, com a melhor escolha de preenchimento de modo a garantir robustez e menor massa, e demorou oito horas de impressão, entretanto após pronto, foi notado que o protótipo ainda precisaria de algumas adaptações ao projeto, porém este modelo inicial já foi bem eficaz para a realização da maioria dos testes.
O outro frame já foi impresso nesta última semana, porém ainda não foi possível a realização de testes nesse novo protótipo devido à sua impressão ainda recente, logo todos os testes citados que necessitavam de uma carcaça para sua realização foram feitos na primeira versão impressa dela.

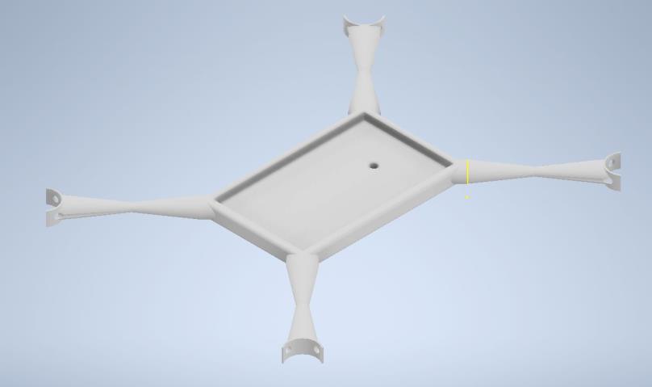
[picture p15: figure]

FIGURA 5. Protótipo do primeiro frame feito no Fusion.

Com a placa eletrônica e a carcaça mecânica prontas, a programação e os testes em relação aos movimentos do drone puderam ser realizados. Dessa forma, além da programação necessária para o controle dos movimentos do drone que foi realizada, foi criado um aplicativo de celular bem simples para testar a execução das seguintes manobras básicas: ir para frente, ir para trás, ir para direita, ir para a esquerda, girar à esquerda, girar à direita, subir e descer. Toda a programação e execução das manobras funcionou perfeitamente, ou seja, quando o botão “ir para frente” era pressionado, por exemplo, os motores da parte traseira aumentavam sua potência e os motores dianteiros diminuíam sua potência, exatamente como necessário para que o drone possa executar tal movimento. Entretanto, quando a função “subir” passou por testes, por mais que os motores aumentem sua potência, assim como desejado, o empuxo gerado não é suficiente e, dessa forma, o drone não sobe.
Algumas hipóteses para a não-realização do voo foram elaboradas, entre elas: o mal balanceamento dos motores, que não giram com a mesma velocidade, o desbalanceamento das peças, podendo haver maior peso em alguma parte, a falta de estabilidade das hélices, pois, como elas não apresentavam um bom encaixe com o frame inicial, elas vibravam muito ou os motores não terem potência suficiente para fazer o protótipo subir.

CONCLUSÕES

A partir dos resultados obtidos, nota-se que o projeto cumpriu parcialmente seus objetivos, pois os autores apresentam certo domínio sobre o funcionamento teórico e prático de um drone, as peças apresentaram um custo menor do que o esperado e os conceitos aprendidos na construção dele, como PWM e controle PID, facilitaram o entendimento nas aulas de eletrônica, elétrica, instrumentação e outras matérias técnicas, além de expandi-lo para outras áreas muito importantes na inovação da indústria, como prototipagem de PCBs e impressão de peças em 3D .
Apenas um objetivo inicial da pesquisa não foi cumprido: a realização de um pequeno voo. Houveram algumas tentativas da execução de um voo, porém nenhuma delas foi efetiva e o projeto necessitaria de melhorias em etapas que apresentam problemas para que esse voo seja efetivamente realizado.
A programação do Arduino e do aplicativo de celular também apresentaram um bom funcionamento e, caso o drone conseguisse subir, com algumas implementações, o smartphone seria totalmente capaz de realizar o controle do drone. Com isso, mostra-se que, apesar que, devido à alguns problemas, o drone não seja capaz de voar, ele demonstra fortes indícios que, com algumas melhorias e mais tempo, sua decolagem seria possível, além de ter sido realizado com um baixo custo e com muitas peças fabricadas na própria instituição, se apresentando como uma excelente ferramenta didática no futuro.

CONTRIBUIÇÕES DOS AUTORES

Todos os autores contribuíram com todas as partes da pesquisa e da elaboração do projeto, além de participarem da escrita e revisão do trabalho e aprovaram a versão submetida.

REFERÊNCIAS

CALIXTO, Felipe. História dos drones: como surgiram? Para que servem? ITARC, 2022. Disponível em: <https://itarc.org/historia-dos-drones/>. Acesso em: 28 de out. de 2023.

MACAJOTECNO. Drone Bluetooth Arduino, Drone Casero y Económico(Tutorial Paso a Paso). YouTube, 27 de ago. de 2018; Disponível em: <https://www.youtube.com/watch?v=Sn5-6SDTLS8>. Acesso em: 29 de out. de 2023.

MASOUD, M.; JARADAT, Y.; FARHOOD, M.; ALMEDALALEH, A.. On Implementing a Low Cost Quadcopter Drone with Smartphone Control. Amman, Jordan: Al-Zaytoonah University of
Jordan, | 2014. | Disponível | em:
<https://www.researchgate.net/publication/301787539_On_Implementing_a_Low_Cost_Quadcopter_Drone_with_Smartphone_Control>. (https://www.researchgate.net/publication/301787539_On_Implementing_a_Low_Cost_Quadcopter_Drone_with_Smartphone_Control) Acesso em: 29 de out. de 2023.

ROMERO, L. E.; POZO, D. F.; ROSALES, J. A. Quadcopter stabilization by using PID controllers. Revista Científica Maskana, Cuenca, v. 5, p. 175-186, 2014.

SILVA, L. P.; CORDEIRO, C. S.. Quadricóptero, Aspectos Gerais e Análises da Propulsão Elétrica. VIII SEGeT - Simpósio de Excelência em Gestão e Tecnologia, Resende/RJ, 2011.

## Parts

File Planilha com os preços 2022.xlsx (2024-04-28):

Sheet: Lista
 | Liste de materiais drone 2
ITEM | Peças: | Quantidade: | UNIDADE | Preço: | Frete: | Total: | Valor por pessoa: | Link do Produto
1 | Arduino nano V3.0 e cabo | 1 | Peça | R$42.00 | R$0.00 | R$42.00 | R$8.40 | https://produto.mercadolivre.com.br/MLB-2159997080-placa-arduino-nano-com-conector-v3-pino-no-soldado-_JM
2 | Acelerômetro Giroscópio 3 Eixos Mpu-6050 Gy-521 Arduino | 1 | Peça | R$22.99 |  | R$22.99 | R$4.60 | https://produto.mercadolivre.com.br/MLB-1970369193-acelermetro-giroscopio-3-eixos-mpu6050-gy-521-nf-_JM
3 | Regulador De Tensão Step Up Mt3608 2a Conversor Dc Dc | 1 | Peça | R$13.99 |  | R$13.99 | R$2.80 | https://produto.mercadolivre.com.br/MLB-2612874692-conversor-regulador-de-tenso-step-up-mt3608-_JM
4 | Módulo Bluetooth Hc-06 Rs232/bluetooth | 1 | Peça | R$35.00 |  | R$35.00 | R$7.00 | https://produto.mercadolivre.com.br/MLB-2612874692-conversor-regulador-de-tenso-step-up-mt3608-_JM
5 | 4 Motores Para Drone Eachine E58 Jy019 - 2 horário 2 anti- horário | 1 | Peça | R$68.40 | R$9.50 | R$77.90 | R$15.58 | https://produto.mercadolivre.com.br/MLB-1311444446-4-motores-para-drone-eachine-e58-jy019-2cw-2ccw-_JM
6 | Bateria Para Drone Avião E Helicópteros 3.7v 1000mah | 1 | Peça | R$76.90 | R$9.50 | R$86.40 | R$17.28 | https://produto.mercadolivre.com.br/MLB-2154865297-bateria-37v-1000mah-drone-lidi-h5p-hq898-k60-hq-905-_JM
7 | Carregador Usb Para Bateria Lipo 1s (3.7v) Com Conector X | 1 | Peça | R$23.00 | R$9.50 | R$32.50 | R$6.50 | https://produto.mercadolivre.com.br/MLB-2015629675-carregador-usb-para-bateria-lipo-1s-37v-com-conector-xh-_JM
8 | Conector macho para a bateria | 1 | Peça | R$26.10 | R$14.10 | R$40.20 | R$8.04 | https://produto.mercadolivre.com.br/MLB-1397933600-conector-jst-ph125-5x-pares-micro-drone-hobby-brinquedo-rc-_JM
9 | MOSFET SI2302 (A2SHB) kit com 10 | 1 | Peça | R$18.00 |  | R$18.00 | R$3.60 | Fornecido pela escola
10 | Diodo retificador IN4007 | 4 | Peça | R$0.92 |  | R$3.68 | R$0.74 | Fornecido pela escola
11 | Resistor 10KΩ | 4 | Peça | R$0.75 |  | R$3.00 | R$0.60 | Fornecido pela escola
12 | Jogo De Hélices 4730 Drone Dji Spark 4 Hélices Paralela | 1 | Peça | R$69.99 |  | R$69.99 | R$14.00 | https://produto.mercadolivre.com.br/MLB-1262373230-dji-spark-kit-4-helices-sunnylife-4730-f-dourada-_JM
13 | Placa de fenolite furada | 10 | Peça | R$2.39 |  | R$23.90 | R$4.78 | Fornecido pela escola (vamos usar apenas 1)
14 | Placa de MDF | 1 |  |  |  |  |  | Fornecido pela escola
 | TOTAL DO PROJETO |  |  |  |  | R$445.65 | R$89.13
 | Link da ideia: https://www.youtube.com/watch?v=Sn5-6SDTLS8
 | arduino | https://shopee.com.br/Arduino-Nano-V3.0-Atmega328p-3.3v-16mhz-CABO-i.428830641.17634836430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
 | shopee:
 | mesma loja:
 | acelerometro | https://shopee.com.br/Aceler%C3%B4metro-E-Girosc%C3%B3pio-3-Eixos-Mpu-6050-Gy-521-Serve-Para-Arduino-Produto-Com-Nota-Fiscal-i.292679151.6873035415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
 | blutu | https://shopee.com.br/M%C3%B3dulo-Bluetooth-Hc06-Hc-06-Slave-Rs232-Arduino-Pic-i.292679151.7872678237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
 | regulador de tensão | https://shopee.com.br/M%C3%B3dulo-Conversor-Dc-dc-Step-Up-Boost-Tens%C3%A3o-Mt3608-i.292679151.8896409607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
 | conectores | https://produto.mercadolivre.com.br/MLB-1397933600-conector-jst-ph125-5x-pares-micro-drone-hobby-brinquedo-rc-_JM

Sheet: Planilha1
 | Liste de materiais drone 2
ITEM | Peças: | Achado?
1 | Arduino nano V3.0 e cabo | X
2 | Acelerômetro Giroscópio 3 Eixos Mpu-6050 Gy-521 Arduino | X
3 | Regulador De Tensão Step Up Mt3608 2a Conversor Dc Dc | X
4 | Módulo Bluetooth Hc-06 Rs232/bluetooth | X
5 | 4 Motores Para Drone Eachine E58 Jy019 - 2 horário 2 anti- horário
6 | Bateria Para Drone Avião E Helicópteros 3.7v 1000mah
7 | Carregador Usb Para Bateria Lipo 1s (3.7v) Com Conector X | X
8 | Conector macho para a bateria
9 | MOSFET SI2302 (A2SHB) kit com 10 | /
10 | Diodo retificador IN4007 | X
11 | Resistor 10KΩ | X
12 | Jogo De Hélices 4730 Drone Dji Spark 4 Hélices Paralela
13 | Placa de fenolite furada | X
14 | Placa de MDF | X

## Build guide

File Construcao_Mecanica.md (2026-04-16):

# Construção Mecânica E Estrutura

## Visão geral

A parte mecânica do projeto foi responsável por transformar a ideia inicial de controle de motores em uma estrutura compatível com um drone experimental. Essa etapa exigiu adaptações porque os primeiros componentes comprados não formavam um conjunto mecânico completo.

## Desafio inicial

Durante a fase de prototipagem, o grupo percebeu que comprar motores e hélices separadamente não resolvia o problema de montagem. Como eram peças de reposição para drones prontos, faltavam elementos de integração entre:

- motor e suporte;
- eixo e hélice;
- conjunto motriz e carcaça.

Esse ponto exigiu uma mudança de estratégia para evitar que o projeto ficasse inviável do ponto de vista construtivo.

## Solução adotada

Em vez de insistir em peças isoladas, foram adquiridos kits prontos contendo hélices, motores e suportes. Isso facilitou:

- a fixação dos motores;
- a compatibilidade mecânica das hélices;
- a modelagem da carcaça;
- a preparação da estrutura para testes.

Com apoio de um professor da área de mecânica, foi possível produzir um protótipo mais consistente para avançar no projeto.

## Carcaça

A carcaça foi pensada com foco em fabricação acessível, por isso a impressão 3D foi escolhida como solução principal. Segundo o histórico do projeto, houve três protótipos até chegar à versão usada no drone final.

As imagens abaixo mostram a evolução visual da estrutura:

<p align="center">
  Estrutura antiga<br/>
  Versão anterior da estrutura vista de cima.
</p>

<p align="center">
  Estrutura final<br/>
  Versão mais refinada da estrutura vista de cima.
</p>

<p align="center">
  Vista frontal do drone<br/>
  Vista frontal do conjunto montado.
</p>

## Componentes mecânicos registrados em imagem

<p align="center">
  Carcaça<br/>
  Exemplo da carcaça utilizada no projeto.
</p>

<p align="center">
  Hélice<br/>
  Hélice utilizada durante o desenvolvimento.
</p>

## Relação com o restante do projeto

A estrutura mecânica está diretamente ligada às outras partes do TCC:

- a placa e a alimentação precisavam caber no corpo do drone;
- o firmware dependia da disposição correta dos quatro motores;
- o comportamento de subida, descida e giro dependia da orientação física desses motores.

Por isso, a construção mecânica não foi apenas acabamento: ela definiu como a eletrônica e o controle poderiam funcionar em conjunto.

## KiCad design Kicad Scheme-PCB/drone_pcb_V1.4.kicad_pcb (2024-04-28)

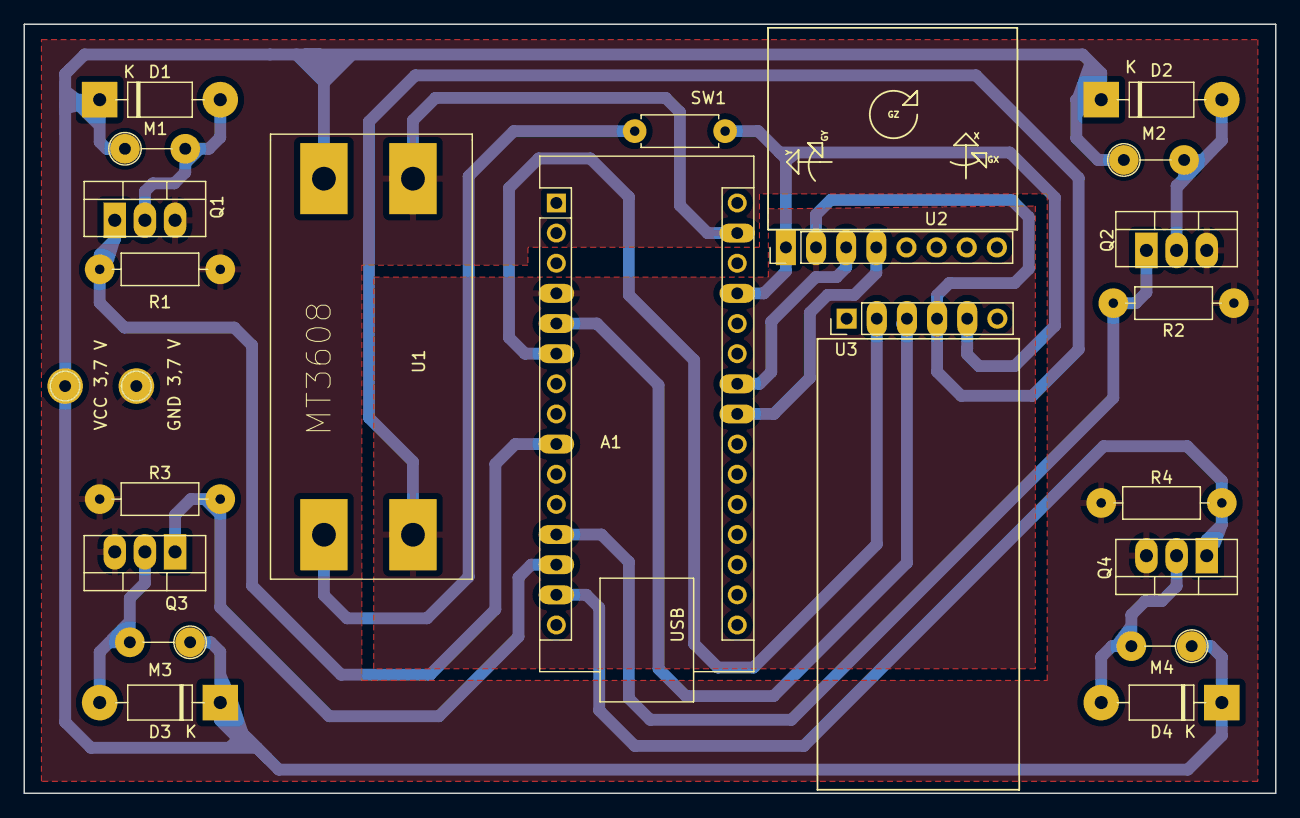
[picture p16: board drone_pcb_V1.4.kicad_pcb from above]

Board: 2 copper layers, 105.4 x 64.8 mm, 23 parts (0 on the bottom side), 17 nets.

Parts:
A1: Arduino Nano; Arduino_Nano
D1, D2, D3, D4: 1N4007; D_DO-41_SOD81_P10.16mm_Horizontal
GND 3,7 V: Pin_D1.0mm_L10.0mm
M1, M2, M3, M4: Motor; R_Axial_DIN0207_L6.3mm_D2.5mm_P5.08mm_Vertical
Q1, Q2, Q3, Q4: IRF640; TO-220-3_Vertical
R1, R2, R3, R4: 1KΩ; R_Axial_DIN0207_L6.3mm_D2.5mm_P10.16mm_Horizontal
SW1: Switch; R_Axial_DIN0207_L6.3mm_D2.5mm_P7.62mm_Horizontal
U1: Step Up; MT3608
U2: Gyroscope; PinHeader_1x08_P2.54mm_Vertical
U3: HC-06; PinHeader_1x06_P2.54mm_Vertical
VCC 3,7 V: Pin_D1.0mm_L10.0mm

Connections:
GND: A1.29 (GND), GND 3,7 V.1, Q1.3 (S), Q2.3 (S), Q3.3 (S), Q4.3 (S), R1.2, R2.2, R3.2, R4.2, U1.2 (V_in-)
GND_5V: A1.4 (GND), U1.4 (V_out-), U2.2 (GND), U3.4 (GND)
M1-: D1.2 (A), M1.2 (-), Q1.2 (D)
M2-: D2.2 (A), M2.2 (-), Q2.2 (D)
M3-: D3.2 (A), M3.2 (-), Q3.2 (D)
M4-: D4.2 (A), M4.2 (-), Q4.2 (D)
PWM_D6: A1.9 (D6), Q1.1 (G), R1.1
PWM_D9: A1.12 (D9), Q2.1 (G), R2.1
PWM_D10: A1.13 (D10), Q3.1 (G), R3.1
PWM_D11: A1.14 (D11), Q4.3 (G), R4.1
RXD: A1.6 (D3), U3.2 (RXD)
SCL: A1.24 (A5), U2.3 (SCL)
SDA: A1.23 (A4), U2.4 (SDA)
TXD: A1.5 (D2), U3.3 (TXD)
VCC: D1.1 (K), D2.1 (K), D3.1 (K), D4.1 (K), M1.1 (+), M2.1 (+), M3.1 (+), M4.1 (+), U1.1 (V_in+), VCC 3,7 V.1
VCC_5V: SW1.1, U1.3 (V_out+)
VCC_5V_SW: A1.27 (+5V), SW1.2, U2.1 (VCC), U3.5 (VCC)

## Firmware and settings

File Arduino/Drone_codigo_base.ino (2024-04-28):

void setup() {
  Serial.begin(9600);
  HC_06.begin(9600); //comm. 7
  start_gyro();
}

void loop() {
  read_gyro();
  /*
  if (HC_06.available() > 0) { //comm. 8
    Serial.write(HC_06.read());
  }
  */  
  while (HC_06.available()==0){}
  read = HC_06.parseInt();
  switch (read){
    case 100:
    start();
    break;
    case 101:
    stop();
    break;
    case 102:
    subir();
    break;
    case 103:
    descer();
    break;
    case 104:
    frente();
    break;
    case 105:
    traz();
    break;
    case 106:
    direita();
    break;
    case 107:
    esquerda();
    break;
    case 108:
    girar_horario();
    break;
    case 109:
    girar_anti_horario();
    break;
    default:
    parado_no_ar(); 
    break;
  }  

}

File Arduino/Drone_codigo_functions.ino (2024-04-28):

void parado_no_ar(){ //comm. 11
  for (vel_atual; vel_atual > vel_parado; vel_atual--) {
    analogWrite(motor_frente_dir, vel_atual); 
    analogWrite(motor_frente_esq, vel_atual);
    analogWrite(motor_traz_dir, vel_atual);
    analogWrite(motor_traz_esq, vel_atual);
    }
  for (vel_atual; vel_atual < vel_parado; vel_atual++) {
    analogWrite(motor_frente_dir, vel_atual); 
    analogWrite(motor_frente_esq, vel_atual);
    analogWrite(motor_traz_dir, vel_atual);
    analogWrite(motor_traz_esq, vel_atual);
    }
}

void start(){ //comm. 1
    if (stoped = 1) {
      for (vel_start; vel_start < 100; vel_start++){
      analogWrite(motor_frente_dir, vel_start); 
      analogWrite(motor_frente_esq, vel_start);
      analogWrite(motor_traz_dir, vel_start);
      analogWrite(motor_traz_esq, vel_start);
      }
    stoped = 0;
    vel_atual = vel_start;
    }
}

void stop(){ //comm. 2
    analogWrite(motor_frente_dir, 0); 
    analogWrite(motor_frente_esq, 0);
    analogWrite(motor_traz_dir, 0);
    analogWrite(motor_traz_esq, 0);
    stoped = 1;
}

void subir(){ //comm. 3
    for (vel_subir; vel_subir < 220; vel_subir++){
    analogWrite(motor_frente_dir, vel_subir); 
    analogWrite(motor_frente_esq, vel_subir);
    analogWrite(motor_traz_dir, vel_subir);
    analogWrite(motor_traz_esq, vel_subir);
    }
  vel_atual = vel_subir;
}

void descer(){ //comm. 4
    for (vel_descer; vel_descer < 220; vel_descer--){
    analogWrite(motor_frente_dir, vel_descer);
    analogWrite(motor_frente_esq, vel_descer);
    analogWrite(motor_traz_dir, vel_descer);
    analogWrite(motor_traz_esq, vel_descer);
    }
  vel_atual = vel_descer;
}

void frente(){ //comm. 5
    for (vel_xy; vel_xy < 25; vel_xy++){
    analogWrite(motor_traz_dir, vel_parado+vel_xy);
    analogWrite(motor_traz_esq, vel_parado+vel_xy);
    analogWrite(motor_frente_dir, vel_parado-vel_xy);
    analogWrite(motor_frente_esq, vel_parado-vel_xy);
    }
  vel_atual = vel_xy;
}

void traz(){ //comm. 5
    for (vel_xy; vel_xy < 25; vel_xy++){
    analogWrite(motor_frente_dir, vel_parado+vel_xy);
    analogWrite(motor_frente_esq, vel_parado+vel_xy);
    analogWrite(motor_traz_dir, vel_parado-vel_xy);
    analogWrite(motor_traz_esq, vel_parado-vel_xy);
    }
  vel_atual = vel_xy;
}

void direita(){ //comm. 5
    for (vel_xy; vel_xy < 25; vel_xy++){
    analogWrite(motor_frente_esq, vel_parado+vel_xy);
    analogWrite(motor_traz_esq, vel_parado+vel_xy);
    analogWrite(motor_frente_dir, vel_parado-vel_xy);
    analogWrite(motor_traz_dir, vel_parado-vel_xy);
    }
  vel_atual = vel_xy;
}

void esquerda(){ //comm. 5
    for (vel_xy; vel_xy < 25; vel_xy++){
    analogWrite(motor_frente_dir, vel_parado+vel_xy);
    analogWrite(motor_traz_dir, vel_parado+vel_xy);
    analogWrite(motor_frente_esq, vel_parado-vel_xy);
    analogWrite(motor_traz_esq, vel_parado-vel_xy);
    }
  vel_atual = vel_xy;
}

void girar_horario(){ //comm. 6
    for (vel_giro; vel_giro < 25; vel_giro++){
    analogWrite(motor_frente_esq, vel_parado+vel_giro);
    analogWrite(motor_traz_dir, vel_parado+vel_giro);
    analogWrite(motor_frente_dir, vel_parado-vel_giro);
    analogWrite(motor_traz_esq, vel_parado-vel_giro);
    }
  vel_atual = vel_giro;
}

void girar_anti_horario(){ //comm. 6
    for (vel_giro; vel_giro < 25; vel_giro++){
    analogWrite(motor_frente_dir, vel_parado+vel_giro);
    analogWrite(motor_traz_esq, vel_parado+vel_giro);
    analogWrite(motor_frente_esq, vel_parado-vel_giro);
    analogWrite(motor_traz_dir, vel_parado-vel_giro);
    }
  vel_atual = vel_giro;
}

void start_gyro(){ //comm. 9
  mpu.begin();
  mpu.setAccelerometerRange(MPU6050_RANGE_8_G);
	mpu.setGyroRange(MPU6050_RANGE_500_DEG);
	mpu.setFilterBandwidth(MPU6050_BAND_21_HZ);
}

void read_gyro(){ //comm. 10
  sensors_event_t a, g, temp;
	mpu.getEvent(&a, &g, &temp);
}

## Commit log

2024-04-28 Arduino Files
2024-04-28 Esquema do Kicad
    [drone_pcb_V1.4.kicad_pcb, drone_pcb_V1.4.kicad_sch]
2024-04-28 Kicad Scheme & PCB
    [drone_pcb_V1.4.kicad_pcb, drone_pcb_V1.4.kicad_sch]
2024-04-28 KicadSchemePCB Reference
2024-04-28 Arduino Reference
2024-04-28 Kicad Scheme & PCB Reference
2024-04-28 Aplicativo de smartphone
2026-04-21 Atualiza codigo Arduino, adiciona videos e detalha documentacao
